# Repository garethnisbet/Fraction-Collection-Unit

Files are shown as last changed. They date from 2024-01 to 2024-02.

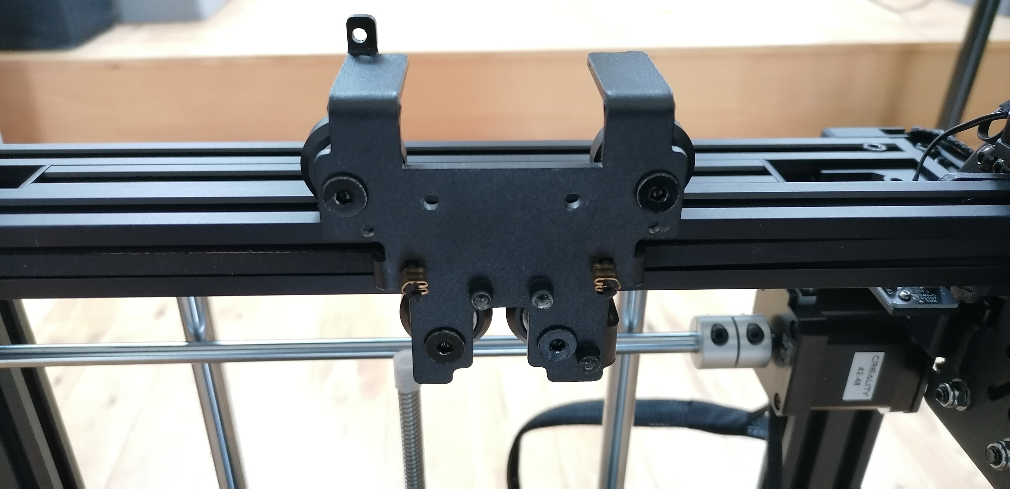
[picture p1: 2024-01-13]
Instructions/IMG_20230724_181359.jpg

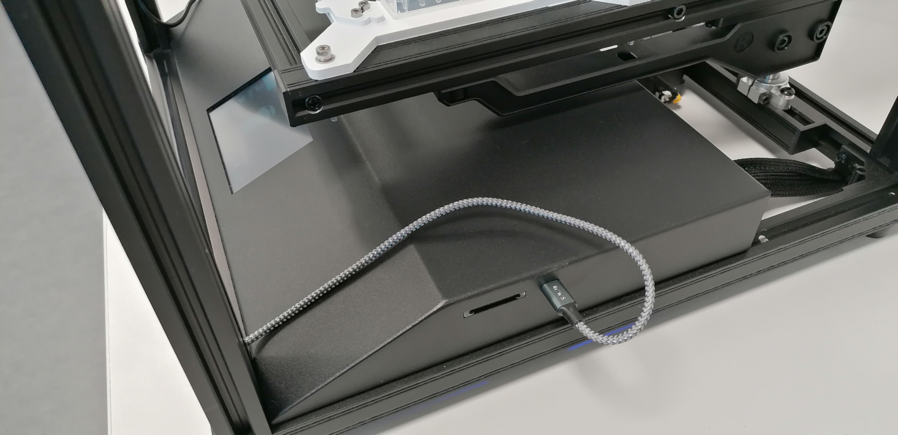
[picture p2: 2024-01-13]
Instructions/IMG_20231009_165833.jpg

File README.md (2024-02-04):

# Fraction-Collection-Unit
Software and CAD files to build a fraction collection unit from a CREALITY Ender-5 S1 3D Printer 

[Control Software](/Python/) - GUI.py is the main file to be executed. 

[CAD-Files](/CAD/STL/) - STL files to be printed.

[Instructions](/Instructions/Instructions.md) - Assembly and User Instructions

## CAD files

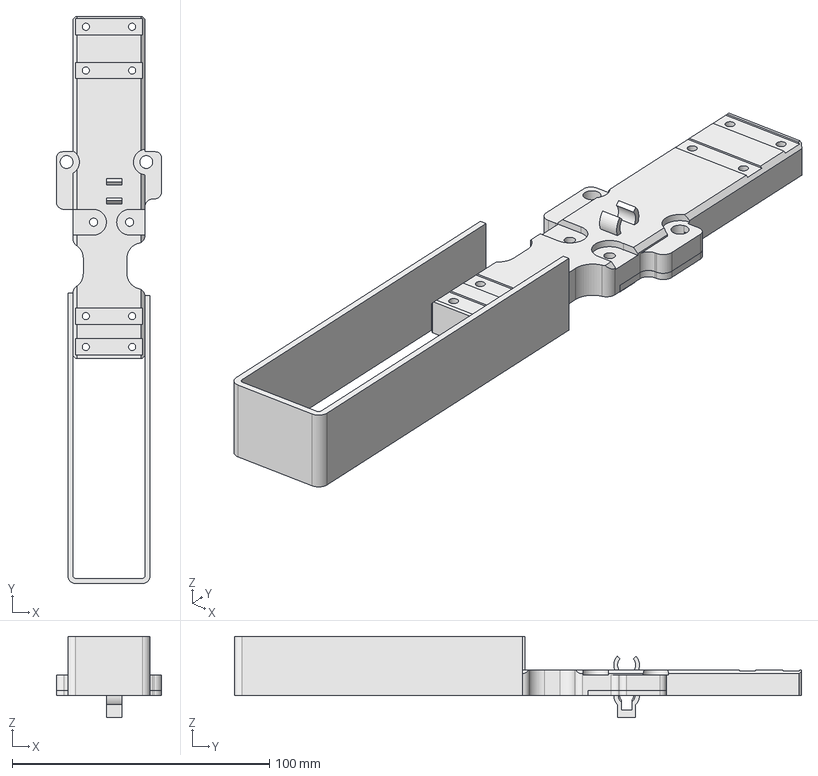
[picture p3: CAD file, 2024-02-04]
CAD/FreeCAD_Files/CapillaryBracket.FCStd
41.0 x 220.5 x 31.6 mm
Pad001002002Body
Pad001002003Body
Pad001002004Body

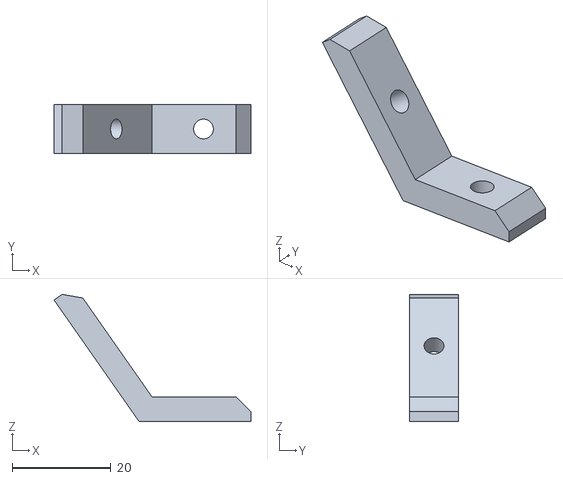
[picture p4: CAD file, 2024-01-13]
CAD/STL/Part_4_ScreenBracket.stl
39.8 x 10.0 x 25.7

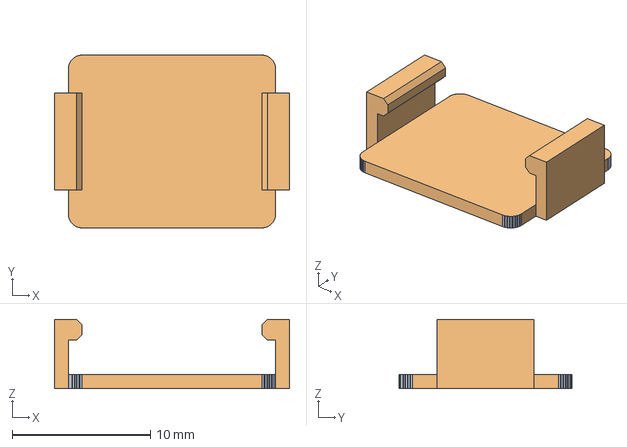
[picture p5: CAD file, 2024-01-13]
CAD/FreeCAD_Files/VShifterCap.FCStd
17.0 x 12.5 x 5.00 mm
Fillet001 (Meshed)

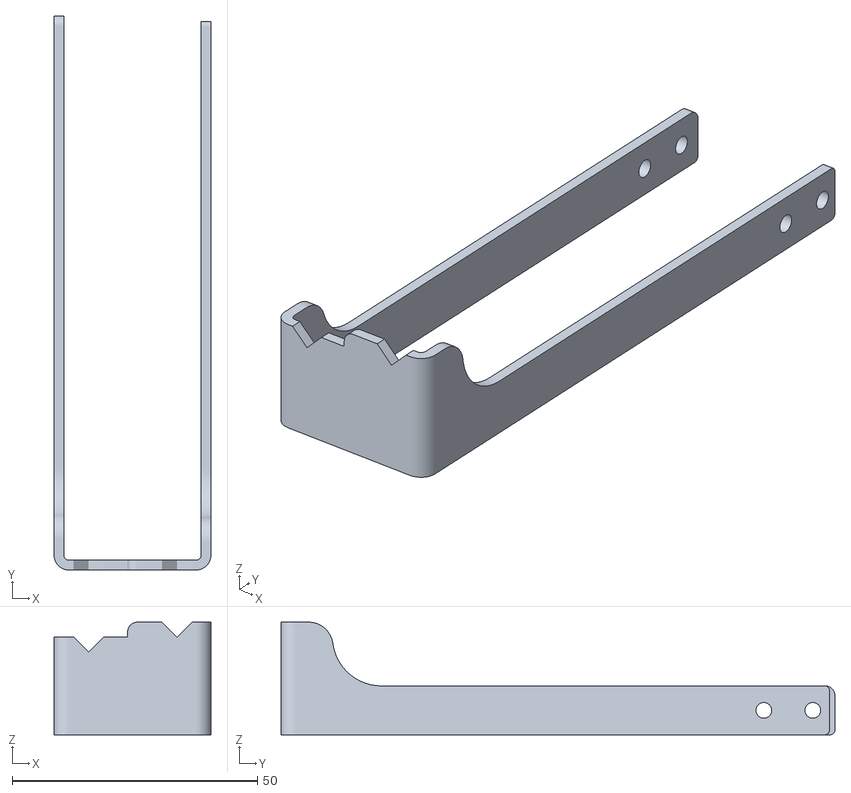
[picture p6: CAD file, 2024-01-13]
CAD/STL/Part_10_CapillaryStabiliser.stl
32.0 x 113.0 x 23.0

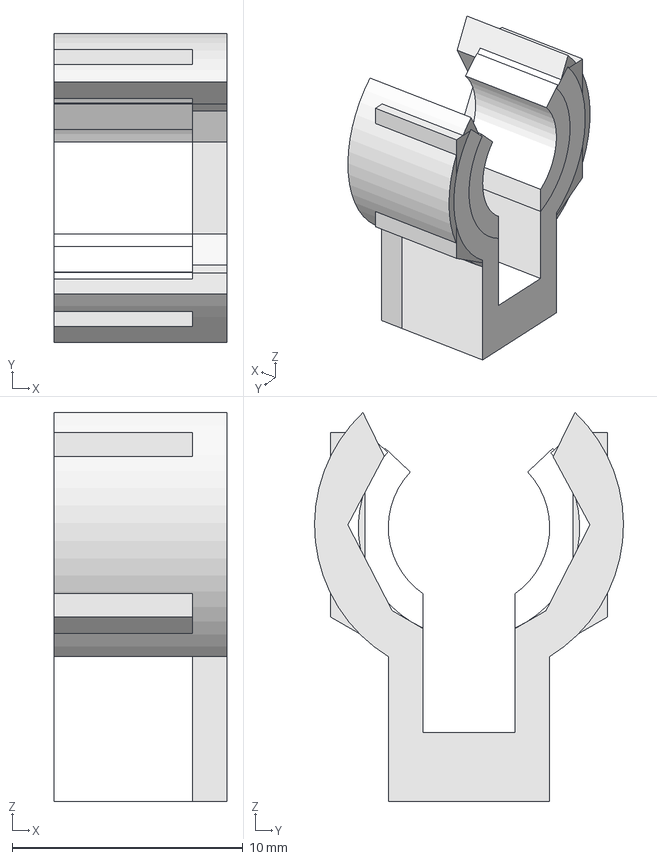
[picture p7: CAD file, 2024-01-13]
CAD/FreeCAD_Files/Clip10mm.FCStd
7.50 x 13.4 x 16.9 mm

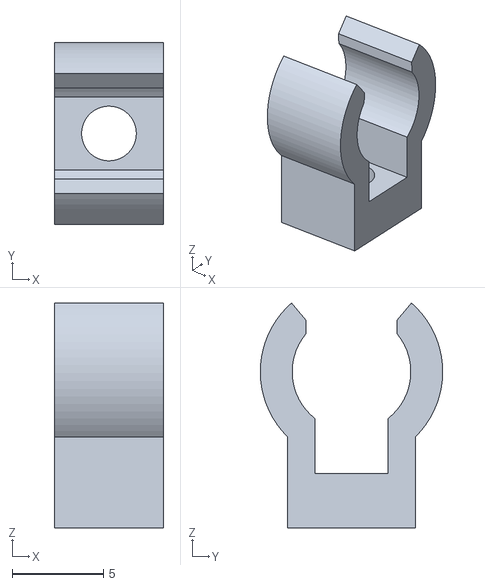
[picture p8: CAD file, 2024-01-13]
CAD/STL/Part_6_LargerClip_Left.stl
6.00 x 10.00 x 12.3

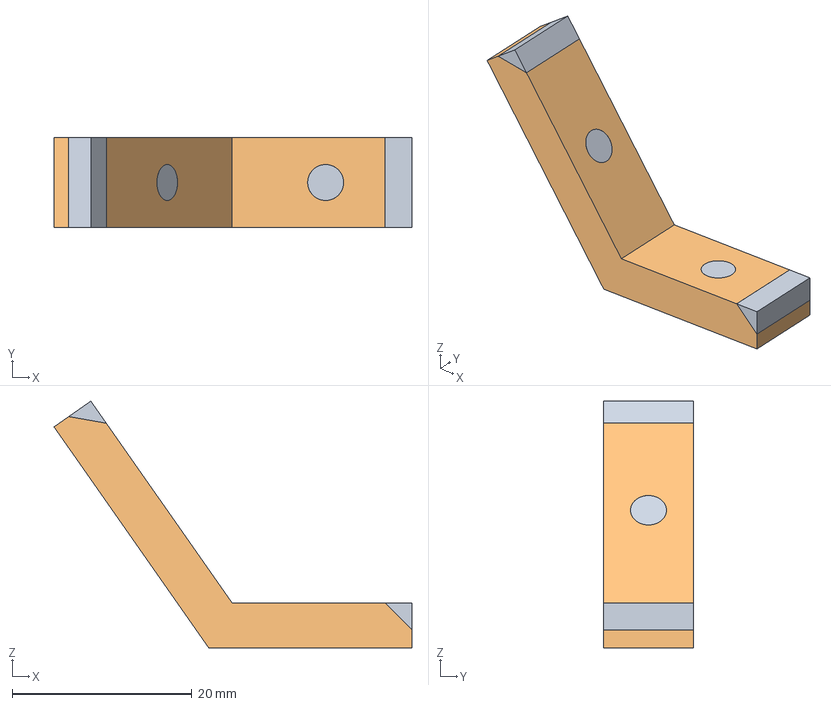
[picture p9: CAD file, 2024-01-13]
CAD/FreeCAD_Files/ScreenBracket.FCStd
39.8 x 10.0 x 27.4 mm
Cut001 (Meshed)

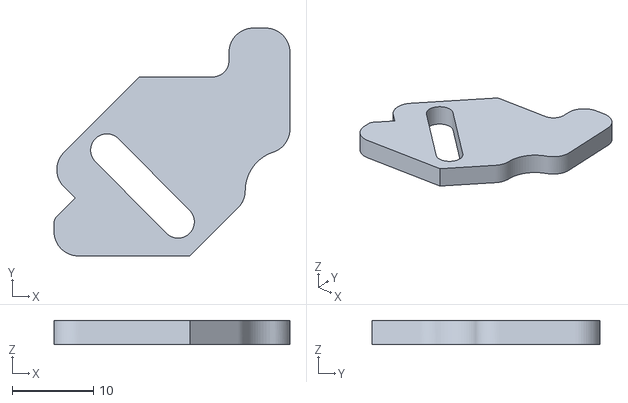
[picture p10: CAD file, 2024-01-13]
CAD/STL/Part_3_ReversableRetainingPlate.stl
29.0 x 28.0 x 3.00

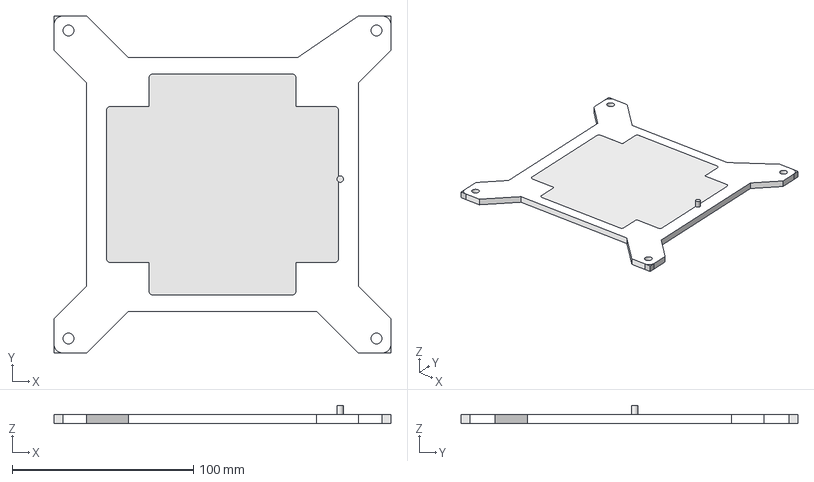
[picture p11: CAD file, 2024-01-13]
CAD/FreeCAD_Files/BoxRetainingPlate.FCStd
186.0 x 186.0 x 10.0 mm

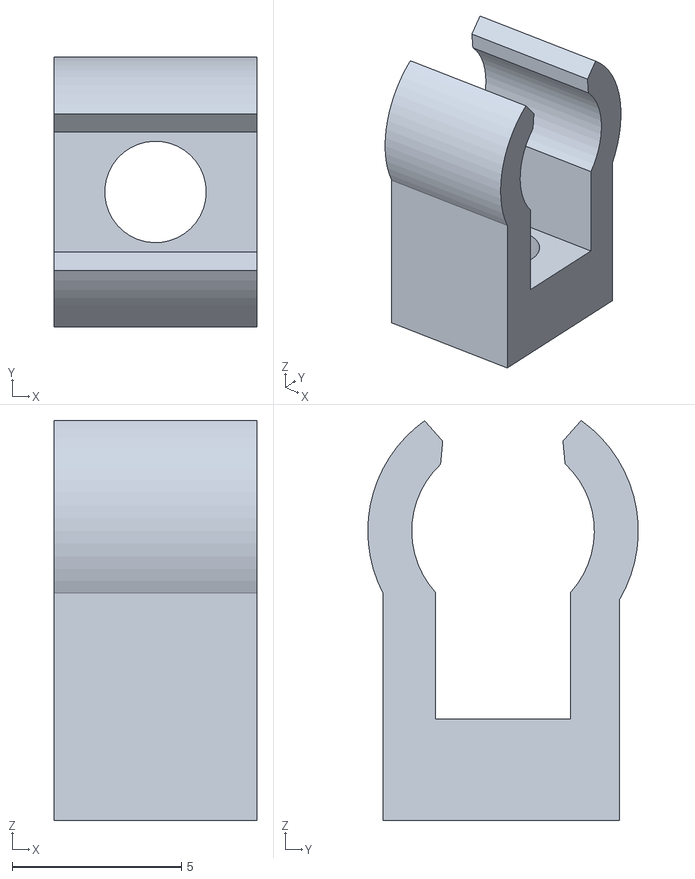
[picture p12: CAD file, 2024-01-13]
CAD/STL/Part_5_SmallClip_Left.stl
6.00 x 8.00 x 11.8

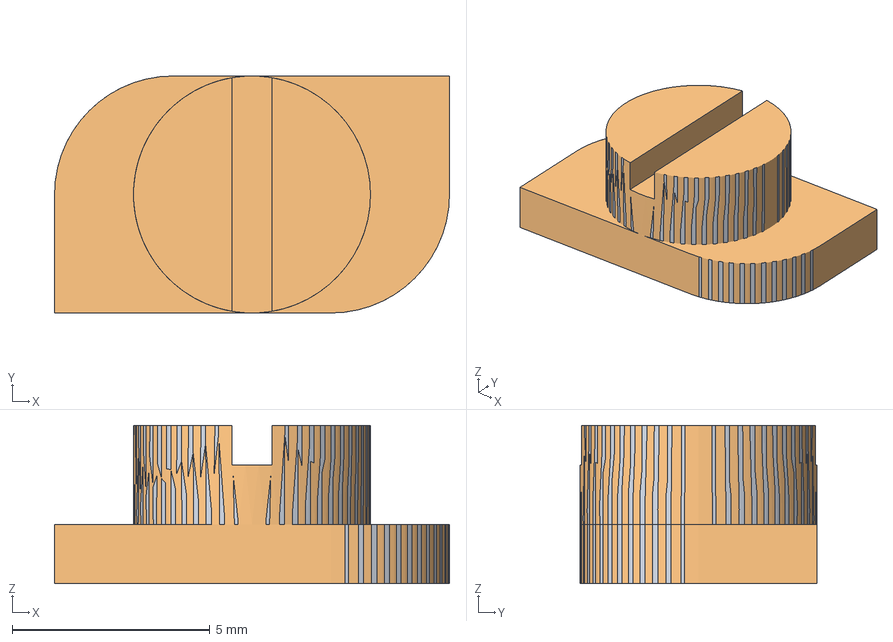
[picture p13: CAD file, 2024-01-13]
CAD/FreeCAD_Files/CableTidyClips.FCStd
10.0 x 6.00 x 4.00 mm
Fusion (Meshed)

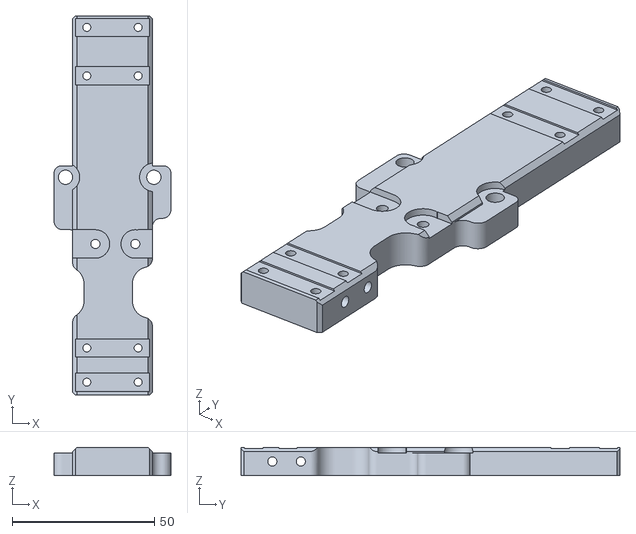
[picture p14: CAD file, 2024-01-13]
CAD/STL/Part_2_CapillaryBracket.stl
41.0 x 133.0 x 10.0

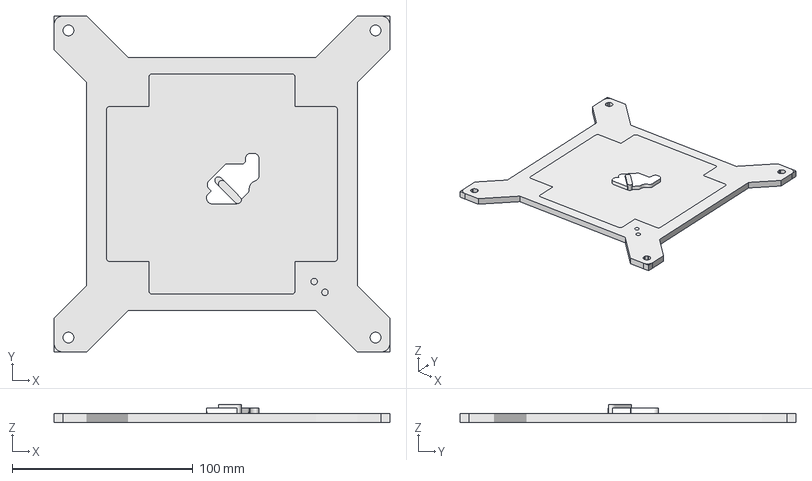
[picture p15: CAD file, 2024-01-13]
CAD/FreeCAD_Files/BoxRetainingPlateV2.FCStd
186.0 x 186.0 x 10.0 mm
Cut006001 (Meshed)
Cut006008002005 (Meshed)

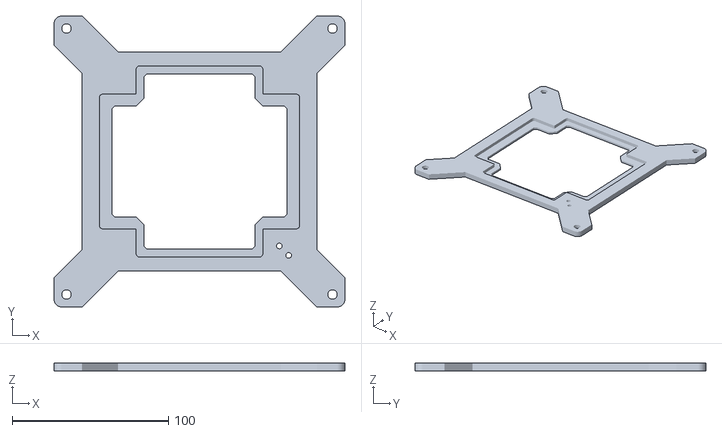
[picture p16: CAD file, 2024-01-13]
CAD/STL/Part_1_FractionBoxBasePlate.stl
186.0 x 186.0 x 5.00

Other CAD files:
CAD/STL/Part_8_LargerClipTall_Right.stl
CAD/STL/Part_7_Tall10mmClip_Right.stl
CAD/STL/Part_11_CableClamps.stl
CAD/STL/Part_9_HexClip_Right.stl

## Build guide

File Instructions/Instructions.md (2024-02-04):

<p align="left">
<h2>Instructions for Fraction Collection Unit</h2>
</p>
1. Build the Creality Ender 5 S1 3D Printer according to the instructions supplied with unit.

Creality Ender 5 S1

2. Download the [CAD Files](../CAD).
3. Download [Cura](https://ultimaker.com/software/ultimaker-cura/) to slice the stl files and generate the G-code for printing.

Printable Parts List

💡 **Note:** Once printing is complete, the print head is going to be removed from the printer so you might want to print a few spare sets before taking this step.

Assemble the Capillary Bracket.

Capillary Bracket Assembly

Remove the print head hotplate and wiring (everything unscrews or unplugs so no cutting is required).

Remove print head and hotplate

Bolt the capillary bracket to print head plate.

Bolt the capillary bracket to prin thead plate

Bolt the base plate to the build platform.

Bolt the capillary bracket to prin thead plate

---
[Install Software](../Python/) - Copy python files into a folder on the Raspberry Pi and run GUI.py.

Screen 1

* The home button homes the motors of the unit
* The dottted grid is used to select the well type. Each type will only fit in the unit one way
* The arrow buttons allow the stages to be jogged
* The stop button is to cancel a motion
* The play button will start the programmed sequence
* The trigger button will start the programmed sequence once a TTL pulse is received
* The save button will save the current position as the origin of the well unit (Note the depth will be relative to this origin)
* The gear button will take you to the settings page

Screen 2

* Pitch is the distance between the centre of two wells
* Depth sets the depth the capillary will travel relative to the origin
* Dwell Time is the time the unit will hold the capillary in the well
* Dwell Time (Sweep) is the time the unit will hold between iterations
* Speed sets the general travel speed of the unit

Screen 3
* Starting Well allows the user to choose a starting well other than the first well
* Number of Wells allows the user to limit the number of wells in the sequence
* Number of Iterations is the number of times the sequence is repeated 

## Usage:
1. Run the GUI.py file
2. Press the home button before running the fraction collection sequence.

💡 **Note:** It is worth creating a desktop launcher for GUI.py. This will allow the machine to be controlled completely through the touchscreen.

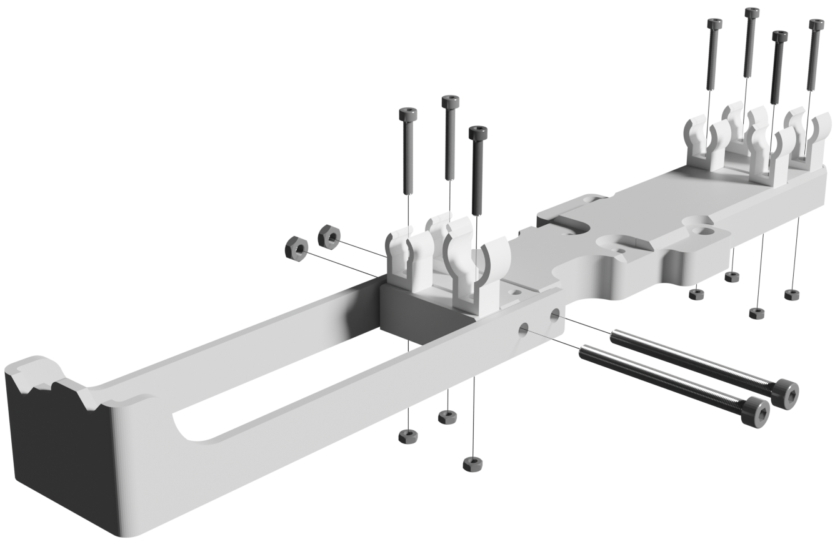
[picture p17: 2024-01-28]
Instructions/CapillaryBracketAssembly.png

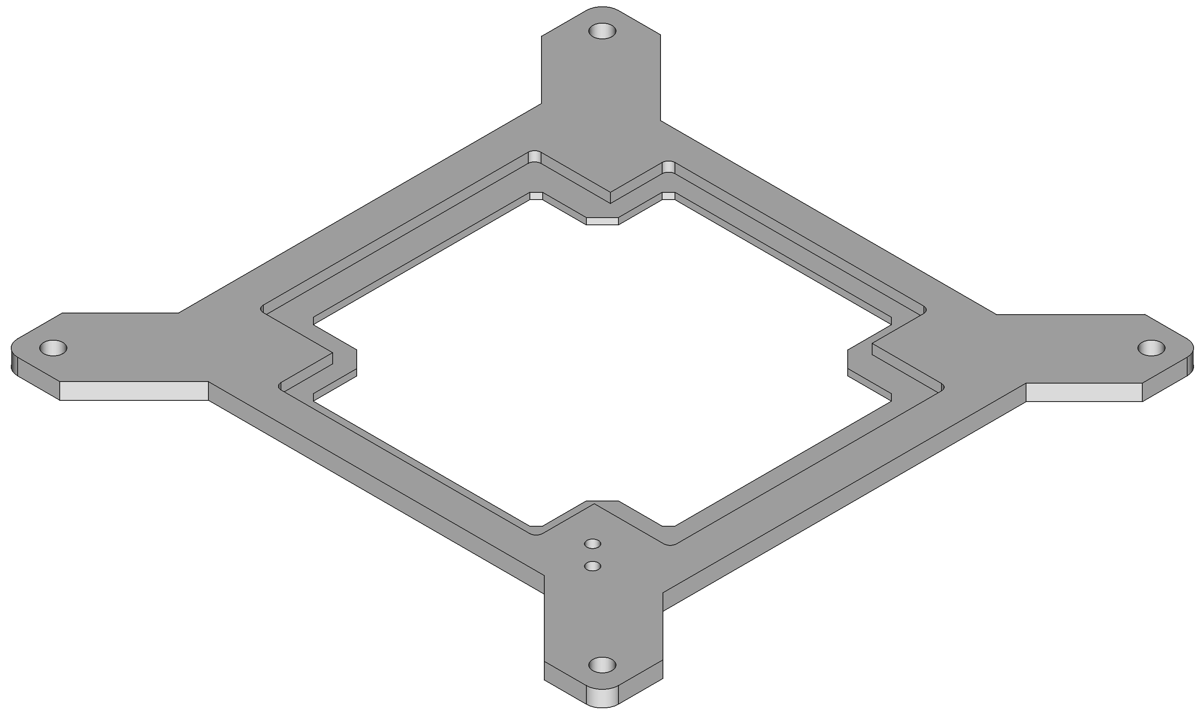
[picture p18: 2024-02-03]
Instructions/BasePlate.png

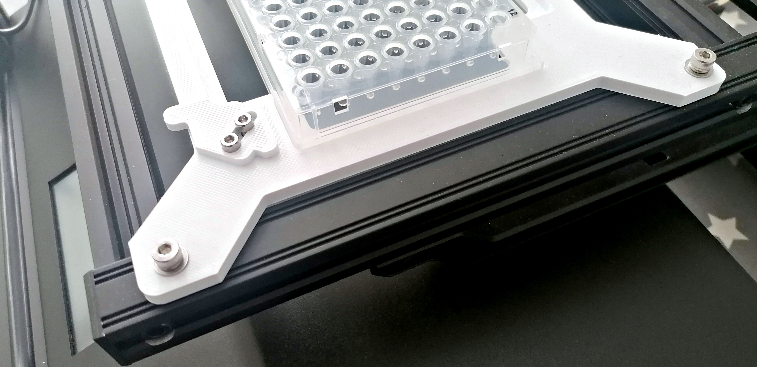
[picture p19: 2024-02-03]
Instructions/IMG_20231008_134651.jpg

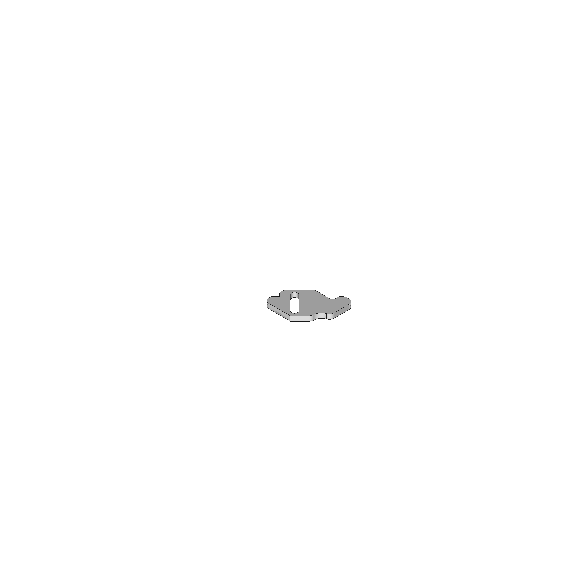
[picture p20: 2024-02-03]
Instructions/WellRetainingClip.png

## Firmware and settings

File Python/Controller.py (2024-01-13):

#Creality 3d printer controller
import serial
import numpy as np
from time import sleep


class Controller(object):
    """ Class for controling the Creality 3d printer over a USB serial connection """
    def __init__(self,port,baudrate):#
        self.port = port
        self.baudrate = baudrate
                                  
    def connect(self):
        self.s = serial.Serial(self.port,self.baudrate)
        
    def disconnect(self):
        self.s.close()
        
    def getPos(self):
        posstatus = self.s.write('M114\n'.encode())
        gotposition = 0
        while not gotposition:
            current_position = self.s.readline().decode().strip()
            if current_position == 'ok':
                gotposition = 0
            elif not current_position.find('busy') == -1:
                gotposition = 0
            else:
                gotposition = 1
        if gotposition:
            xval = float(current_position[current_position.find('X')+2:current_position.find('Y')-1])
            yval = float(current_position[current_position.find('Y')+2:current_position.find('Z')-1])
            zval = float(current_position[current_position.find('Z')+2:current_position.find('E')-1])
        else:
            xval = np.nan
            yval = np.nan
            zval = np.nan
        return xval, yval, zval

    def setPos(self,x_val,y_val,z_val,feedrate = 500):
        self.x_val = x_val
        self.y_val = y_val
        self.z_val = z_val
        gcode = 'G1X'+str(x_val)+'Y'+str(y_val)+'Z'+str(z_val)+'F'+str(feedrate)+'\n'
        self.s.write(gcode.encode())

    def sendGCODE(self,gcode):
        self.s.write(gcode.encode())
        sleep(0.1)

    def rmove(self, axis, step, direction,feedrate = 500):
        gcode = 'G91 \nG1'+axis+str(step*direction)+' F'+str(feedrate)+'\nG90\n'
        self.s.write(gcode.encode())
        
    def enable(self):
        gcode = 'M22 \nM21\n'
        self.s.write(gcode.encode())
        
    def home(self):
        self.s.write('G28\n'.encode())
        print('Homed')
        
    def stop(self):
        self.s.write('M410\n'.encode())
    
    def readline(self):
        return self.s.readline().decode().strip()
  

        

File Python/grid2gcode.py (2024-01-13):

import numpy as np
class grid2gcode(object):
    """ create gcode from specified grid """
    def __init__(self,origin, shape, pitch, feedrate, depth, dwelltime):#
        self.origin = origin
        self.shape = shape
        self.pitch = pitch
        self.feedrate = feedrate
        self.depth = depth
        self.dwelltime = dwelltime
        self.orientation = 0
        self.xdata = []
        self.ydata = []

    def setOrientation(self, orientation):
        self.orientation = orientation
        
                                  
    def create(self):
        # Assuming pitch is +ve
        gcode = ['G1 X{:.2f} Y{:.2f} Z{:.2f} F{} \n'.format(self.origin[0],self.origin[1],self.origin[2],self.feedrate[0])]
        if self.orientation == 0:
            xstart = self.origin[0]
            xend = self.origin[0]+(self.pitch[0]*(self.shape[0]))
            xstep = self.pitch[0]
            self.xdata = list(np.arange(xstart,xend,xstep))
            
            ystart = self.origin[1]
            yend = self.origin[1]+(-self.pitch[1]*(self.shape[1]))
            ystep = -self.pitch[1]

            self.ydata = list(np.arange(ystart,yend,ystep))
            xdata = self.xdata

            for ii in list(range(len(self.ydata))):
                for iii in list(range(len(self.xdata))):
                    gcode += ['G1 X{:.2f} Y{:.2f} F{} \n'.format(xdata[iii],self.ydata[ii],self.feedrate[0])]
                    gcode += ['G1 Z{:.2f} F{} \n'.format(self.origin[2]+self.depth,self.feedrate[1])]
                    gcode += ['G4 S{:.2f} \n'.format(self.dwelltime)]
                    gcode += ['G1 Z{:.2f} F{} \n'.format(self.origin[2],self.feedrate[1])]
                xdata.reverse()
        elif self.orientation == 1:
            xstart = self.origin[0]
            xend = self.origin[0]+(-self.pitch[0]*(self.shape[1]))
            xstep = -self.pitch[0]
            self.xdata = list(np.arange(xstart,xend,xstep))
            
            ystart = self.origin[1]
            yend = self.origin[1]+(-self.pitch[1]*(self.shape[0]))
            ystep = -self.pitch[1]
            self.ydata = list(np.arange(ystart,yend,ystep))
            ydata = self.ydata

            for ii in list(range(len(self.xdata))):
                
                for iii in list(range(len(self.ydata))):
                    gcode += ['G1 X{:.2f} Y{:.2f} F{} \n'.format(self.xdata[ii],ydata[iii],self.feedrate[0])]
                    gcode += ['G1 Z{:.2f} F{} \n'.format(self.origin[2]+self.depth,self.feedrate[1])]
                    gcode += ['G4 S{:.2f} \n'.format(self.dwelltime)]
                    gcode += ['G1 Z{:.2f} F{} \n'.format(self.origin[2],self.feedrate[1])]
                ydata.reverse()
            
        return gcode
        


# origin, shape, pitch, feedrate, depth, dwelltime = [5,8,10], [12,8], [0.91, 0.91], [1000,500], -5, 1

# g2g = grid2gcode(origin, shape, pitch, feedrate, depth, dwelltime).create()
